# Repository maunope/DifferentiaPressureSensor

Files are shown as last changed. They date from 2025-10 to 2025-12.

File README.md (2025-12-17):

# ESP32-S3 Differential Pressure Datalogger

This project is a datalogger built on the ESP32-S3 platform using the ESP-IDF framework. It's designed to read environmental data from a BMP280 sensor, display it on an OLED screen with a menu-driven interface, and log the data to an SD card. The system uses a DS3231 Real-Time Clock (RTC) for accurate timestamping and exposes the SD card as a USB Mass Storage Device for easy data access.

Please refer to the following main guides for usage guidance and documentation:

*   **[User Interface Guide](UI_GUIDE.md)**: A complete guide to the on-screen menu system and controls.
*   **[Web UI Guide](WEB_UI.md)**: Instructions for using the web interface to manage files.
*   **[Software Architecture](SOFTWARE_ARCHITECTURE.md)**: An in-depth look at the software design, tasks, and communication mechanisms.
*   **[Board Design](BOARD_DESIGN.md)**: Details on the custom PCB, hardware components, and pinout.

## Overview

### Key Features

*   **Sensor Datalogging**: Periodically reads:
    *   Temperature and atmospheric pressure from a BMP280 sensor.
    *   Differential pressure from an Omron D6F-PH sensor.
    *   LiPo battery voltage and percentage.
    *   Device uptime in seconds.
*   **Dual-Mode Data Smoothing**: Configurable Kalman filtering is applied to all sensor readings. The system uses two distinct sets of filter parameters for "Normal" and "High-Frequency" logging modes. All parameters (`kf_*_q`, `kf_*_r`, `kf_*_q_hf`, `kf_*_r_hf`) can be customized in `config.ini`. If high-frequency (`_hf`) parameters are omitted, the system automatically calculates sensible defaults based on the normal-frequency values.
*   **SD Card Storage**: Logs sensor data to CSV files on an SD card, with support for file rotation based on size (1MB limit, approx. 2 weeks of recording at 1 point per minute).
*   **Real-Time Clock (RTC)**: Utilizes a DS3231 RTC for accurate timestamps. The system can synchronize its time from the RTC on startup.
*   **OLED Display & UI**: Features a menu-driven user interface on an OLED display, controlled by a rotary encoder with a push-button. The UI displays:
    *   Real-time sensor data (temperature, pressure, differential pressure, battery status).
    *   Current local timestamp (CET/CEST).
    *   SD card write status.
    *   Persistent status icons for battery level, charging status, and SD card write errors.
    *   A settings menu to manage the RTC, SD card, view configuration, and display a QR code linking to the project repository.
*   **NTP Time Sync**: Can synchronize the RTC with an NTP server over Wi-Fi.
*   **Web Server**: Can start a web server to allow downloading and previewing logged data files directly from a web browser.
*   **Multiple Sampling Modes**: Supports "Normal", "High Frequency", and "Paused" logging modes, selectable via the UI.
*   **Robust Power Management**: Implements a command-driven deep sleep cycle to conserve battery. The datalogger task explicitly signals when it's safe to sleep, preventing race conditions and ensuring data integrity. The device wakes up on a timer for the next log or via user interaction. A safety threshold on battery voltage avoids data corruption when measured battery voltage is too low to guarantee stable power to the 3.3V rail.
*   **Web File Management**: The web interface allows users to list, preview, download, and delete log files directly from the device.
*   **Exclusive File System Access**: To prevent data corruption, the system ensures that only one component (Datalogger, Web Server, or USB Mass Storage) can access the SD card at a time. For example, starting the web server will pause the datalogger, and connecting the device to a PC will disable both the web server and the datalogger.
*   **Configuration & Persistence**:
    *   **Permanent Settings**: Key parameters like sleep intervals, Wi-Fi credentials, and sensor models can be configured via a `config.ini` file on the SD card. These settings are loaded into flash memory and persist across reboots.
    *   **Session Settings**: UI-selected modes (like "High Frequency" or "Paused") are stored in RTC memory and persist through deep sleep cycles, but will be reset to their default values after a full power cycle or reboot.
*   **RTOS-based**: Built on FreeRTOS, with separate tasks for data logging and UI rendering for a responsive and robust application.

### Hardware Components

*   **Microcontroller**: ESP32-S3
*   **Sensors**:
    *   BMP280: Barometric Pressure and Temperature (I2C)
    *   Omron D6F-PH: Differential Pressure (I2C)
*   **Storage**:
    *   MicroSD Card Slot (SPI)
*   **Display**:
    *   OLED Display (I2C)
*   **User Input**:
    *   Rotary Encoder with Push-button
*   **Timekeeping**:
    *   DS3231 Real-Time Clock (I2C)
*   **Power**:
    *   LiPo Battery with a voltage divider for monitoring.

For more details on the custom PCB, see the [board design documentation](BOARD_DESIGN.md).

## Hardware Notes

### DS3231 RTC Configuration

Please be aware that this firmware automatically configures any connected DS3231 Real-Time Clock with specific default settings upon boot. These settings are optimized for low-power operation and resilience. For details on the exact register values being set, please refer to the `readme.md` file located in the `lib/i2c_ds3231/` directory.

### Usage

1.  **Configuration**: Copy the `config_sample.ini` file to the root of your SD card and rename it to `config.ini`. Edit this file to set your Wi-Fi credentials, sensor model, and other parameters.
2.  **Operation**: The device is controlled with the rotary encoder and its built-in push-button. For a detailed explanation of the menu system and on-screen information, please see the User Interface Guide.
3.  **Web Interface**: When the web server is active, you can manage files from your browser. See the Web UI Guide for more details.
## Software & Libraries

*   **Framework**: ESP-IDF
*   **RTOS**: FreeRTOS
*   **Component Management**: Dependencies like `qrcode` and `tinyusb` are managed by the ESP-IDF Component Manager via the `idf_component.yml` file. The `esp_tinyusb` component for USB Mass Storage is enabled and configured directly through `menuconfig`, with settings reflected in the PlatformIO build profiles.
*   **Software Architecture**: The project is built on a multi-tasking architecture using FreeRTOS. For a detailed explanation of the tasks and how they communicate, see the Software Architecture Guide.
*   **Custom Libraries (located in `lib/`)**: This project uses a modular structure with several custom libraries. Click on a library name to see its specific documentation.
    *   `config_manager`: Handles loading configuration from an INI file.
    *   `i2c_bmp280`: Driver for the BMP280 sensor.
    *   `i2c_d6fph`: Driver for the Omron D6F-PH sensor.
    *   `i2c_ds3231`: Driver for the DS3231 RTC.
    *   `i2c_oled`: Driver for the OLED display.
    *   `kalman`: kalman filter implementation.
    *   `lipo_battery`: Logic for reading battery voltage.
    *   `ntp_client`: Helper for synchronizing time from an NTP server.
    *   `rotary_encoder`: Driver for the rotary encoder input.
    *   `spi_sdcard`: High-level manager for SD card operations and USB MSC.
    *   `ui`: Manages the complete user interface, menu, and pages. See the UI Guide.
    *   `web_server`: Provides a web interface for downloading log files. See the Web UI Guide.
    *   `wifi_manager`: Centralizes Wi-Fi connection and disconnection logic.

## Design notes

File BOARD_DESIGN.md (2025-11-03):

# Differential Pressure Datalogger - PCB Design

This directory contains the KiCad project files for the custom PCB designed for the ESP32-S3 Differential Pressure Datalogger.

## Board Overview

The board is designed to be a compact, battery-powered datalogging platform. It integrates all the necessary components for sensing, data storage, user interaction, and power management.

The following diagram shows how the main peripherals are connected to the ESP32 microcontroller:

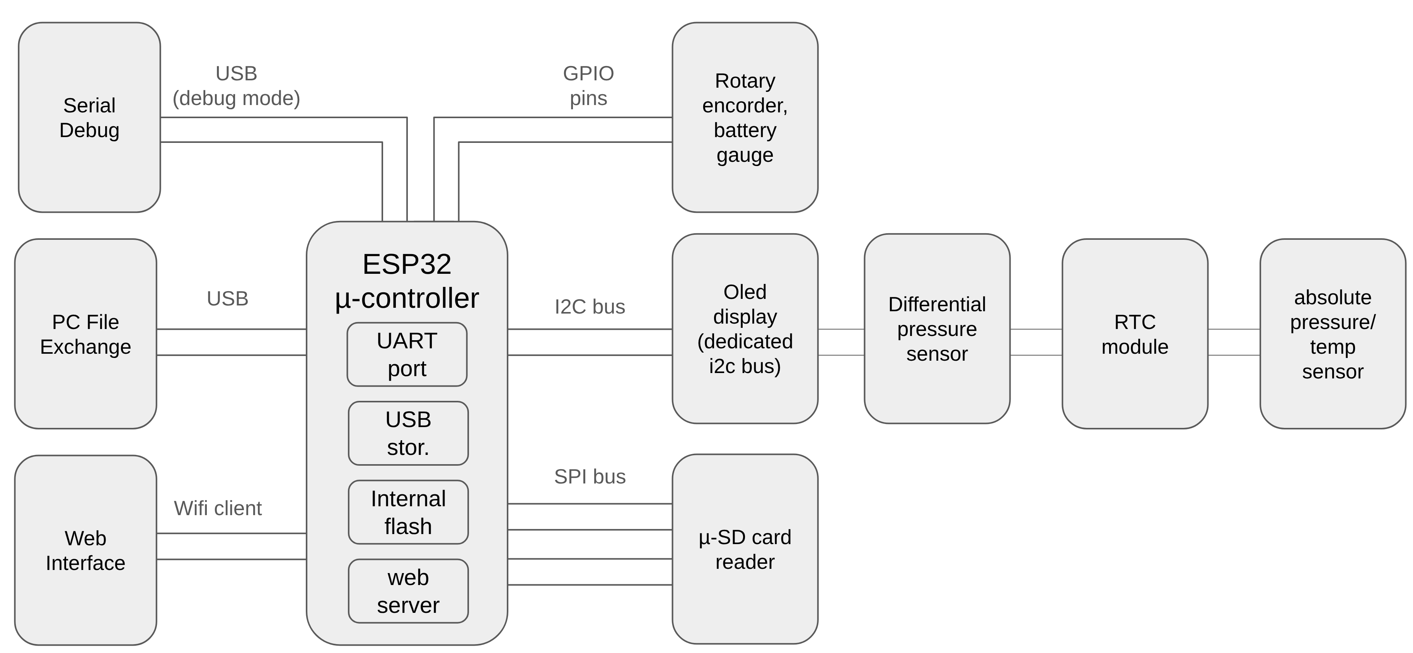
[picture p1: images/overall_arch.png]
Overall Architecture


The following image shows a render of the custom PCB layout:

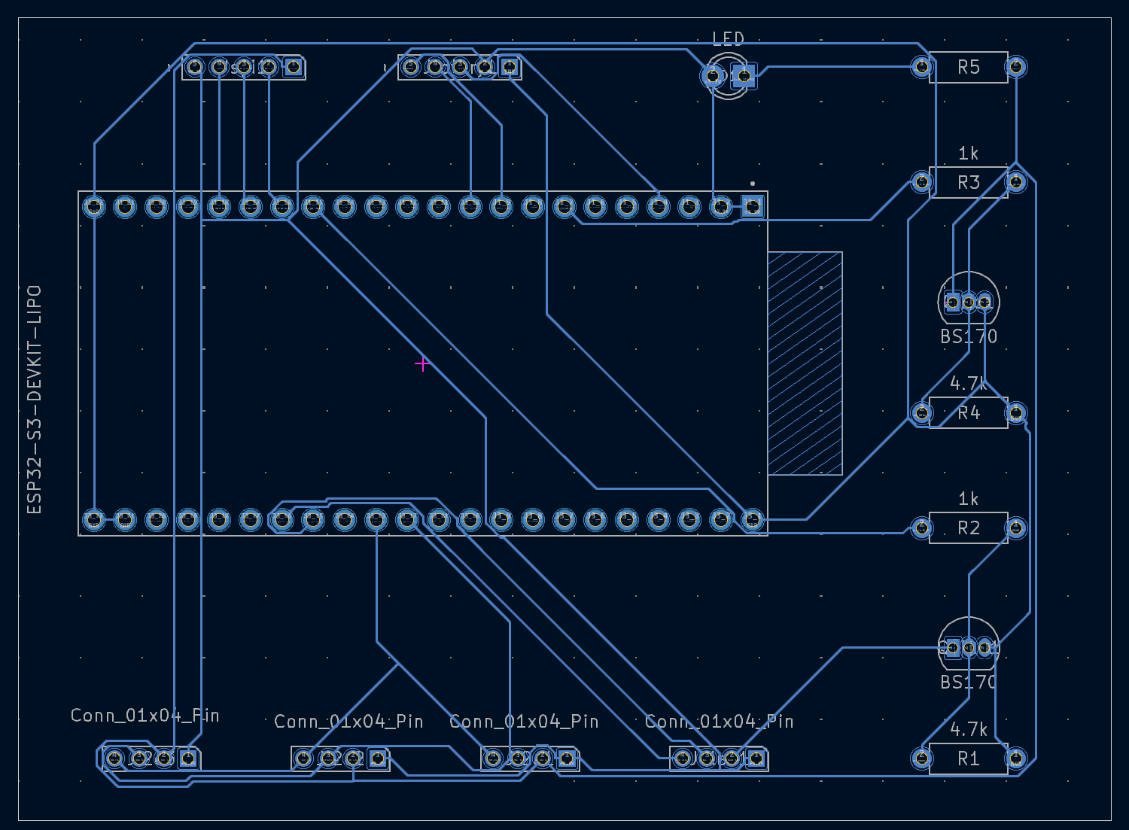
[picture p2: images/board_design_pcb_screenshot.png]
PCB Layout Screenshot


## Hardware & Compatibility

This project was developed and tested on the following hardware:

*   **[OLIMEX ESP32-S3-DevKit-LiPo](https://github.com/OLIMEX/ESP32-S3-DevKit-LiPo)**: This board was used for much of the development. It features a built-in LiPo battery charger and management circuit, which works seamlessly with the software's battery monitoring capabilities.
*   **Generic ESP32-S3 Dev-board**: Testing was also performed on a no-brand ESP32-S3 development board.

The software is designed to be portable and is expected to work on any ESP32-S3 based board with the correct peripheral connections. The only feature that is highly dependent on the specific board's hardware implementation is the **battery gauging**, which requires a specific voltage divider circuit on the ADC pin as detailed in the pinout table.

### Key Components

*   **Microcontroller**: ESP32-S3-WROOM-1 module.
*   **Sensors**:
    *   I2C BMP280 for atmospheric pressure and temperature.
    *   I2C [Omron D6F-PH](https://omronfs.omron.com/en_US/ecb/products/pdf/en-d6f_ph.pdf) for differential pressure. The software is written to support the `D6F-PH-0505AD3` (+/- 50 Pa), `D6F-PH-0025AD1` (+/- 250 Pa), and `D6F-PH-5050AD4` (+/- 500 Pa) models, selectable via the `config.ini` file.
*   **Timekeeping**: A generic **DS3231** I2C Real-Time Clock (RTC) module with a backup battery.
*   **Storage**: A **SPI bus** microSD card reader for data logging.
*   **User Interface**:
    *   2.42 Inch 128x64 I2C OLED display. (these often come configured for SPI and require some jumper soldering to be repurposed for I2C). 
    *   A standard 5-pin rotary encoder with a push-button.
*   **Connectivity**: USB-C for programming, power, and accessing the SD card as a Mass Storage Device.
*   **Power**: 3.7V LiPo battery with integrated protection circuitry. 

Apart form the Omron differential pressure sensor, all other devices are run of the mill stuff, easy to source from Aliexpress/Amazon and often icluded in esp32/Arudino starter kits. 

### Power System

All components used in this project are **3.3V devices**. It is critical **not to mix 5V and 3.3V logic levels** in the same circuit, as this would damage the components, especially the Omron D6F-PH sensor which is not 5V tolerant.

The custom PCB design primarily consists of pin headers (I2C, SPI, etc.) to connect these components in their breakout board form. The other components on the board are standard passives like resistors, along with BS170 MOSFETs for power control and JST connectors for external hardware.

The BS170 mosfets can be replaced with pretty much any N channel mosfet that can be turned on with 3.3V gate voltage, **IRLZ34N** have been tested and work just fine.

## Hardware Deep Sleep Implementation

To achieve ultra-low power consumption (under 1mA) during deep sleep, the board implements a hardware power-gating strategy. Two separate GPIO pins are used to control the power supply to different sets of peripherals:

*   **`DEVICES_POWER` (GPIO 15)**: This pin controls a MOSFET that supplies power to the main I2C bus peripherals (BMP280, D6F-PH) and the SD card. Before entering deep sleep, the ESP32 sets this pin low, completely cutting power to these components. This is the primary mechanism for power saving, reducing consumption by over 85%. The DS3231 RTC is on a separate, always-on power rail to maintain timekeeping.
*   **`OLED_POWER` (GPIO 16)**: This pin independently controls the power to the OLED display. This allows the screen to be turned off after a period of inactivity, even while the rest of the device is still running and logging data.

This hardware design allows the software to aggressively manage power, ensuring long battery life for a portable datalogger.

## Pinout

The following table details the GPIO connections for the main peripherals.

| Peripheral | Pin Name | ESP32-S3 GPIO | Notes |
| --- | --- | --- | --- |
| **Power Control** | `DEVICES_POWER` | 7 | Controls power to sensors/peripherals |
| | `OLED_POWER` | 15 | Controls power to the OLED display |
| | `I2C0_SCL` | 36 | |
| | `I2C0_SDA` | 35 |
| **OLED I2C Bus** | `I2C1_SCL` | 45 | Dedicated bus for the display |
| | `I2C1_SDA` | 48 | |
| **SD Card (SPI)** | `SPI_MOSI` | 12 | Standard SPI pins for SD card |
| | `SPI_MISO` | 10 | |
| | `SPI_CLK` | 11 | |
| | `SPI_CS` | 13 | |
| **Rotary Encoder**  | `ENC_A` | 4 | |
| | `ENC_B` | 16 | |
| | `ENC_BTN` | 17 | Also used as a deep sleep wakeup pin  |
| **Battery Monitor** | `BATT_PWR` | 5 | Detects external power |
| | `BATT_ADC` | 6 | ADC input for voltage measurement |

## I2C Bus Considerations

When extending the I2C bus, especially with longer cables, it's crucial to consider the impact of cable capacitance. Excessive capacitance can degrade signal integrity, leading to communication errors or complete bus failure. It is  recommended to keep total I2C bus length below 2-3 meters (total of all paralleled cables) to stay within acceptable capacitance limits.

To improve reliability over longer distances, several strategies can be employed:

*   **Pull-up Resistor Values**: The I2C bus requires pull-up resistors on both SDA and SCL lines. Keeping these values relatively low can help overcome capacitance effects. This board has been successfully tested with a total pull-up resistance of 3 kOhm (measured between Vcc and SDA/SCL pins) on a 4-meter cable length, operating at 100 kHz.
*   **Avoid Too Low Pull-ups**: While lower pull-up values are generally better for longer cables, care must be taken not to go too low. If I2C devices on the bus happen to have small internal pull-up resistors, they can effectively parallel with external resistors. The combined equivalent resistance should not cause overcurrents on i2c pins as going too low can lead to excessive current draw and signal distortion, 6mA capable pins should never be paired with less than 1kohm total pull up resistance.
*   **Cable Type**: Using twisted pair cables for SDA/SCL lines can significantly reduce noise and maintain signal integrity over distance. This practice helps in keeping the total bus capacitance below the recommended 400 picofarad limit for standard I2C operation.

For applications requiring longer I2C bus lengths or higher speeds, dedicated I2C bus extenders or buffers might be necessary.

## Design Files

This project was designed using **KiCad**. The main files are:

*   `DifferentialPressureSensor.kicad_pro`: The main KiCad project file.
*   `DifferentialPressureSensor.kicad_sch`: The schematic file.
*   `DifferentialPressureSensor.kicad_pcb`: The PCB layout file.

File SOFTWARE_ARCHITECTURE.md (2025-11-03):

# Software Architecture

This document provides an overview of the software architecture for the Differential Pressure Datalogger project. The system is built on the FreeRTOS real-time operating system, leveraging a multi-tasking design to ensure responsiveness and modularity.

## Core Principles

The architecture is designed around a few key principles:

*   **Separation of Concerns**: Each major function (data logging, user interface, input handling) is managed by its own dedicated task.
*   **Asynchronous Communication**: Tasks communicate primarily through message queues, which prevents tasks from blocking each other and keeps the system responsive.
*   **Shared State with Protection**: A central data structure, protected by a mutex, holds the current state and sensor data, providing a single source of truth for all tasks.

## Task Overview

The system is composed of several key tasks, each with a specific role and priority. In FreeRTOS, a higher number indicates a higher priority.

| Task Name | Priority | Core Responsibility |
| --- | :---: | --- |
| `rotary_encoder_task` | 7 | Hardware input processing (highest priority). |
| `uiRender_task` | 6 | User interface rendering and event handling. |
| `main_task` | 5 | Central controller and state management. |
| `datalogger_task` | 5 | Sensor reading and data logging to the SD card. |
| Web Server Task |  (ESP) | Handles HTTP requests (managed by `esp_http_server`). |

### `rotary_encoder_task` (Priority 7)

This is the highest-priority application task. Its sole responsibility is to capture and decode hardware interrupts from the rotary encoder. It detects rotation (clockwise/counter-clockwise) and button events (short and long presses), debounces them, and sends them as messages to the `uiRender_task` for processing. This high priority ensures that no user input is ever missed, even if other tasks are busy.

### `uiRender_task` (Priority 6)

This task is the heart of the user interface. It has a higher priority than the main logic to ensure the display is always responsive to user input.

*   **Receives**: Raw input events (e.g., `UI_EVENT_CW`, `UI_EVENT_BTN`) from the `rotary_encoder_task` via the `ui_event_queue`.
*   **Reads**: The shared `g_sensor_buffer` to get the latest data for display.
*   **Sends**: High-level application commands (e.g., `APP_CMD_START_WEB_SERVER`) to the `main_task` via `g_app_cmd_queue`.
*   **Responsibilities**: Manages menu navigation, renders all pages, and displays feedback from long-running commands (e.g., "Loading...").

### `main_task` (Priority 5)

This task acts as the central coordinator for the entire system. It runs a state machine that manages the device's overall behavior.

*   **Receives**: High-level commands from the `uiRender_task` via `g_app_cmd_queue`.
*   **Responsibilities**:
    *   Orchestrates complex sequences, such as starting the web server (which involves pausing the datalogger and connecting to Wi-Fi).
    *   Manages the power-saving logic, including inactivity timers and the deep sleep sequence.
    *   **Arbitrates SD Card Access**: Ensures exclusive access to the file system between the datalogger, web server, and USB Mass Storage.
    *   Ensures exclusive access to the SD card by preventing the web server from starting if USB Mass Storage is active, and stopping the web server if USB is connected.
    *   Handles system-level requests like NTP time sync and SD card formatting.

### `datalogger_task` (Priority 5)

This task handles all sensor reading and data storage.

*   **Receives**: Commands like `DATALOGGER_CMD_PAUSE_WRITES` and `DATALOGGER_CMD_RESUME_WRITES` from the `main_task`.
*   **Writes**: The latest sensor readings and status information to the shared `g_sensor_buffer`.
*   **Responsibilities**:
    *   Handles file system commands sent from other tasks, such as deleting a log file (`DATALOGGER_CMD_DELETE_FILE`).
    *   Periodically wakes up to read data from the BMP280, D6F-PH, and battery monitor.
    *   Formats the data into CSV format.
    *   Writes the data to the SD card.

## Communication Mechanisms

### Shared Data Buffer

*   **`g_sensor_buffer`**: A global `struct` that holds the most recent state of the entire system. This includes sensor values, battery status, SD card statistics, and web server status.
*   **`g_sensor_buffer_mutex`**: A mutex that protects `g_sensor_buffer` from concurrent access. Any task that needs to read from or write to the buffer must first acquire this mutex. To keep the system responsive, tasks are designed to hold the mutex for the shortest possible time.

### Message Queues

*   **`g_app_cmd_queue`**: Used to send high-level commands *to* the `main_task`. This decouples the UI from the application logic. For example, the UI sends `APP_CMD_START_WEB_SERVER`, and the `main_task` handles the multi-step process of making that happen.
*   **`g_datalogger_cmd_queue`**: Used to send specific commands *to* the `datalogger_task`, such as pausing or resuming SD card writes.
*   **`ui_event_queue`**: A dedicated queue for the `uiRender_task`. The `rotary_encoder_task` places raw input events here for the UI to process.
*   **`g_i2c_bus_mutex`**: Protects the main I2C bus (`I2C_NUM_0`), which is shared by multiple sensors (BMP280, DS3231, D6F-PH). This prevents tasks from attempting to communicate on the bus at the same time.
*   **`g_command_status_mutex`**: Protects the `g_command_status` variable. This variable is used for asynchronous feedback between the `main_task` and the `uiRender_task` for long-running operations like formatting the SD card or syncing with an NTP server.

## Exclusive File System Access

The SD card is a critical shared resource. To prevent file system corruption, all file system operations are protected by a dedicated mutex (`g_sdcard_mutex` in the `spi_sdcard` library). This ensures that only one operation (e.g., writing a log line, deleting a file, listing files for the web server) can occur at a time, even when multiple tasks are running concurrently.

There are three components that can access the SD card:

1.  **Datalogger Task**: The default owner, responsible for writing sensor data logs.
2.  **Web Server**: Allows a user to list, download, and delete files via a web browser.
3.  **USB Mass Storage (MSC)**: Allows a host computer to mount the SD card as a drive, which has the highest priority.

The access rules are as follows:

*   **USB Mass Storage has absolute priority.** If the device is connected to a PC and the SD card is mounted by the host computer, the `main_task` will automatically stop the web server (if it's running) and will prevent both the web server and the datalogger from starting. This gives the host computer exclusive control to ensure a stable connection and prevent data corruption.
*   **Concurrent Operation with Mutex Protection**: The `datalogger_task` (writing logs) and the Web Server task (listing/deleting files) can run at the same time. They do not need to pause each other. The low-level `g_sdcard_mutex` serializes their access to the SD card, preventing conflicts. For example, if the web server is deleting a file, the datalogger's attempt to write a new line will block on the mutex until the deletion is complete.
*   **Special Operations (Formatting)**: For destructive, long-running operations like formatting the SD card, the `main_task` still explicitly pauses the `datalogger_task` to ensure the file system is completely idle.
*   **Safe Ejection**: When connected as a USB Mass Storage device, it is highly recommended to use your operating system's "Eject" or "Safely Remove Hardware" feature before physically unplugging the device. This ensures all file operations are complete and helps prevent data corruption on the SD card.

This mutex-based approach provides more efficient and responsive operation than pausing entire tasks, while still guaranteeing data integrity.

## Power Management & Deep Sleep

The device is designed for low-power operation by using a deep sleep cycle. The `main_task` is responsible for managing the sleep and wake logic.

### Entering Deep Sleep

The device will enter deep sleep when all of the following conditions are met:

1.  The UI has been inactive for a configurable period (`inactivity_timeout_ms`), which causes the UI task to suspend.
2.  The `datalogger_task` has completed a write to the SD card and sent an `APP_CMD_LOG_COMPLETE_SLEEP_NOW` command to the `main_task`.
3.  The web server is not active at the time the sleep command is processed.

The sleep sequence is as follows:

1.  The `main_task` receives the `APP_CMD_LOG_COMPLETE_SLEEP_NOW` command.
2.  It verifies that the UI is suspended and the web server is inactive.
3.  It sends a `DATALOGGER_CMD_PAUSE_WRITES` command to the `datalogger_task`.
4.  It waits for the `datalogger_task` to confirm it has suspended itself.
5.  Once paused, it de-initializes the SD card, Wi-Fi, and cuts power to the main peripheral power rail.
6.  It saves critical state variables (e.g., the timestamp of the last write, total uptime) to RTC memory, which persists through deep sleep.
7.  It configures two wakeup sources for the ESP32-S3: 
    *   **GPIO**: A press on the rotary encoder button.
    *   **Timer**: A timer set by the `sleep_duration_ms` configuration value.
8.  It calls `esp_deep_sleep_start()` to enter deep sleep.

### Waking Up

The device wakes up when either the timer expires or the user presses the button.

*   **On Timer Wakeup**: The device wakes up to perform a data logging cycle. The UI remains off to conserve power. After the logging is complete, it immediately prepares to enter deep sleep again.
*   **On GPIO Wakeup (User Activity)**: The device performs a full boot sequence, powering on the OLED display and initializing the UI. The user can then interact with the device normally.

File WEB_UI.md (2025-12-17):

# Web User Interface Guide

This document explains the features and functionality of the web-based user interface, which can be accessed when the device's web server is active.

## Overview

The web UI provides a convenient way to monitor the device, view live data, and manage log files directly from a web browser on a computer or smartphone connected to the same Wi-Fi network.

The interface is divided into three main sections:
1.  **Live Sensor Data**: A real-time dashboard of sensor readings.
2.  **File Browser**: A list of all data log files stored on the SD card.
3.  **File Previewer**: An interactive tool for viewing the contents of log files without downloading them.
## Live Sensor Data

The panel at the top of the page displays the most recent data read from the device's sensors. This data is automatically refreshed every 5 seconds and includes:

*   **Timestamp**: The current date and time from the device's RTC.
*   **Temperature**: Ambient temperature in Celsius.
*   **Pressure**: Atmospheric pressure in kilopascals (kPa).
*   **Diff. Pressure**: Differential pressure in Pascals (Pa).
*   **Battery**: Voltage, percentage, and charging status.

If the web page fails to fetch data, a banner will appear with a "Retry" button to re-establish the connection.

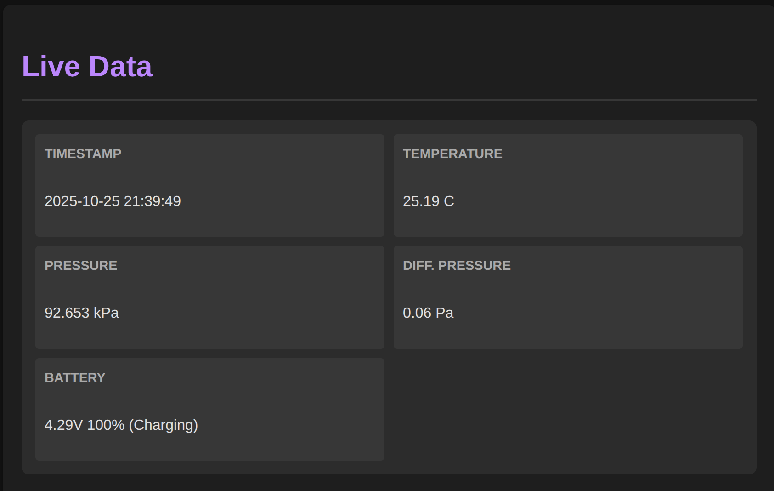
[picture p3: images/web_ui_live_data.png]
Live Sensor Data


## File Browser

This section lists all files found on the SD card, sorted by the most recently modified. Each entry provides the following information and actions:

*   **Filename**: The name of the log file. Clicking this link will download the file directly to your computer.
*   **File Metadata**: The file size and the date it was last modified.
*   **Preview Button**: Opens the interactive File Previewer for that file.
*   **Delete Button**: Permanently deletes the file from the SD card after a confirmation prompt.

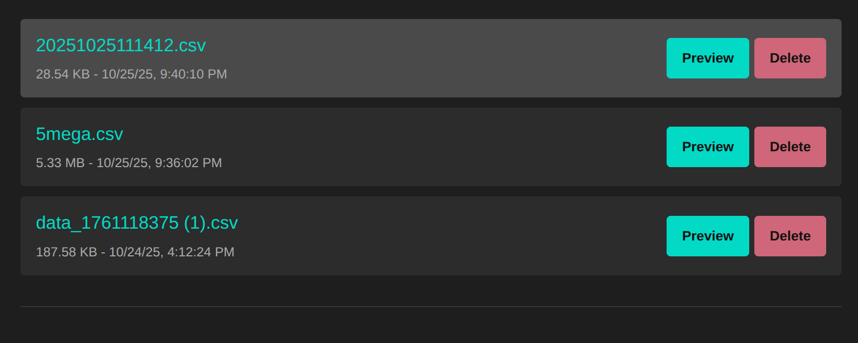
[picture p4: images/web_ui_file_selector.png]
File Browser


## File Previewer

The File Previewer is a powerful tool for inspecting log data directly on the device.

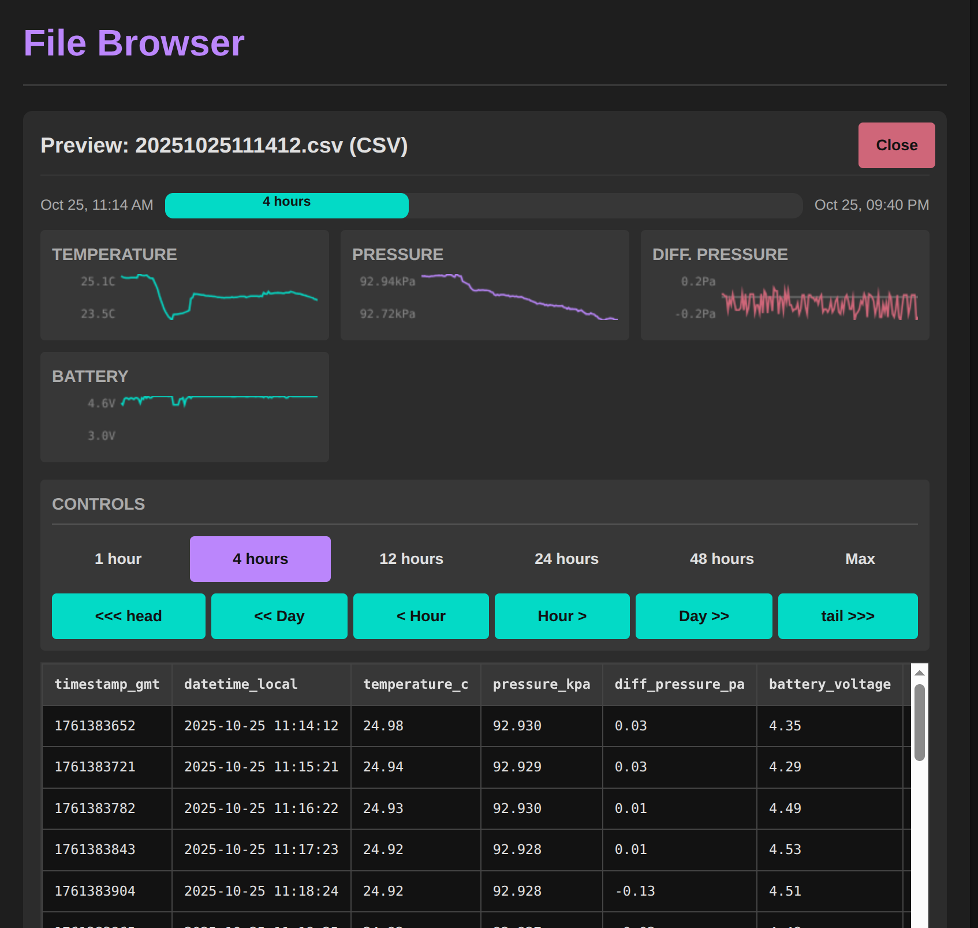
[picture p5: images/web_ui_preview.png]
File Previewer


### CSV vs. Raw Text Files

The previewer automatically detects the file type:
*   **CSV Files**: If the file is recognized as a CSV log, it will be displayed in a scrollable table with a header. At the top, sparkline graphs provide a quick visual summary of the data currently loaded in the table.
*   **Non-CSV Files**: If the file is not a standard log file (e.g., `config.ini`), its contents will be displayed as plain, raw text.

### Navigating CSV Data

The sparkline graphs are designed to provide a quick, at-a-glance overview of the data trends within the currently loaded time window. This is especially useful for getting a quick sense of the data in the field with minimal effort, even without an internet connection.

For a more thorough analysis, especially with very large files, it is recommended to download the CSV file and use a dedicated tool. You can open the file in any spreadsheet program (like Microsoft Excel, Google Sheets, or LibreOffice Calc) or use online data visualization tools that allow you to upload CSV files, such as:
*   CSV Plot
*   Draxlr

Additionally, mobile apps like Smart CSV are excellent for processing and visualizing entire data files on the go.

The previewer is designed to handle very large files efficiently by only loading small chunks of data at a time.

#### Time Window and Navigation

The previewer has two sets of controls for navigation:

1.  **Scale Buttons (`1 hour`, `4 hours`, etc.)**: These buttons set the **size of the time window** to load. When you select a scale, the previewer fetches a chunk of data that covers that duration.
    *   **Performance Note**: For very large files, using a wide time window (like "24 hours" or "Max") can be sluggish, as the device needs to process more data to find the correct starting point. For quicker navigation, it's often better to use a smaller window and jump through the file.

2.  **Jump Buttons (`<<< head`, `< Hour`, `Day >>`, etc.)**: These buttons perform **windowed navigation**, allowing you to "jump" through the file. When you click one of these buttons:
    *   The currently displayed data is **replaced** with a new chunk of data from a different part of the file, based on the button you clicked (e.g., `Day >>` jumps forward 24 hours).
    *   This is the fastest way to move through large files, as it avoids loading all the data in between.

For extremely large or dense files, the most efficient way to perform a full analysis is to download the file and open it on your computer.

#### Data View Toggle

When previewing a CSV file, the sparkline graphs can display either the raw sensor data or the smoothed (Kalman-filtered) data. The filter parameters are configured in `config.ini`.

*   **Smoothed View (Default)**: This view shows the data after it has been processed by the Kalman filter. It is generally cleaner and easier to interpret, as it removes sensor noise.
*   **Raw View**: This view shows the unprocessed data directly from the sensors. It is useful for diagnostics and for observing the unfiltered sensor behavior.

You can switch between these views using the **"Smoothed"** and **"Raw"** toggle buttons located in the "Controls" panel above the data table.

The system uses two distinct sets of Kalman filter parameters: one for normal logging (`kf_*_q`, `kf_*_r`) and one for high-frequency logging (`kf_*_q_hf`, `kf_*_r_hf`). All of these can be configured in `config.ini`. If the high-frequency parameters are not specified, the device will automatically calculate appropriate defaults based on the normal-frequency settings, providing a good baseline for both logging speeds out-of-the-box.

#### Scrolling

You can use your mouse or trackpad to scroll through the data that is currently loaded in the preview table. Scrolling does **not** load new data from the file. To navigate to a different part of the file, you must use the **Scale** and **Jump** buttons.

When you click a navigation button (e.g., `Day >>`), the currently displayed data is replaced with a new chunk from the file, and the scroll position is reset to the top of the new chunk.

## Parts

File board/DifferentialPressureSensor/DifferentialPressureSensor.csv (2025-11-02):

Reference | Qty | Value | DNP | Exclude from BOM | Exclude from Board | Footprint | Datasheet
D1 | 1 | LED |  |  |  | LED_THT:LED_D3.0mm | ~
Ji2c1,Ji2c2,Ji2c3,Joled1 | 4 | Conn_01x04_Pin |  |  |  | Connector_PinHeader_2.00mm:PinHeader_1x04_P2.00mm_Vertical | ~
Jrotary1,Jspi1 | 2 | ~ |  |  |  | Connector_PinHeader_2.00mm:PinHeader_1x05_P2.00mm_Vertical | ~
Qi2c1,Qoled1 | 2 | BS170 |  |  |  | Package_TO_SOT_THT:TO-92_Inline | https://www.onsemi.com/pub/Collateral/BS170-D.PDF
R1,R4,R5 | 3 | 4.7k |  |  |  | Resistor_THT:R_Axial_DIN0207_L6.3mm_D2.5mm_P7.62mm_Horizontal | ~
R2,R3 | 2 | 1k |  |  |  | Resistor_THT:R_Axial_DIN0207_L6.3mm_D2.5mm_P7.62mm_Horizontal | ~
U1 | 1 | ESP32-S3-DEVKIT-LIPO |  |  |  | Olimex ESP32 S3 LiPo Devkit:XCVR_ESP32-S3-DEVKIT-LIPO

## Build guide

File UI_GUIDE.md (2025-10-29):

# User Interface Guide

This guide explains how to navigate and use the user interface of the Differential Pressure Datalogger. The UI is controlled using a single rotary encoder with a built-in push-button.

## Controls

*   **Rotate Clockwise (CW)**: Navigates **down** in menus or cycles forward through pages.
*   **Rotate Counter-Clockwise (CCW)**: Navigates **up** in menus or cycles backward through pages.
*   **Short Press**:
    *   In a menu, it **selects** the highlighted item. This may enter a submenu, trigger an action, or show an information page.
    *   On an information page (like "About" or "Sensor Data"), it **returns to the main menu**.
*   **Long Press (Hold for ~1 second)**: From any menu screen, it acts as a "home" button, immediately returning you to the **Sensor Data screen**.

## Status Icons

The top-right corner of the screen displays persistent icons that provide at-a-glance information about the device's status.

*   **Battery Icon**: Shows the current battery charge level. The fill level represents the remaining charge.

    ```
    +--------------------+
    | Main Menu      [[]] <-- Battery Icon
    | ...                |
    +--------------------+
    ```

*   **Charging Icon**: When the device is connected to USB power, a lightning bolt symbol appears **inside** the battery icon.

    ```
    +--------------------+
    | Main Menu      [[#]] <-- Charging Icon
    | ...                |
    +--------------------+
    ```

*   **SD Card or Sensor Error**: If the device fails to write to the SD card or a sensor fails to initialize or read, an **error icon (!!)** will appear to the **left** of the battery icon. This icon persists until the condition is resolved.

    ```
    +--------------------+
| Main Menu   !! [[]] <-- Error Icon
    | ...                |
    +--------------------+
    ```

*   **USB Connection Icon**: When the device is connected to a computer and mounted as a USB drive, a **USB plug icon** will appear. This indicates that the SD card is accessible from your computer. While this icon is active, other status icons (like SD Error, Paused, and High-Frequency) are hidden, as logging is temporarily suspended.

*   **Paused Icon**: When data logging is paused via the "Sampling Mode" menu, a **pause icon (||)** will appear to the left of the battery icon. In this mode, the device will not write any new data to the SD card and will not enter deep sleep automatically.

    ```
    +--------------------+
| Main Menu   || [[]] <-- Paused Icon
    | ...                |
    +--------------------+
    ```

*   **High-Frequency Mode**: When enabled, a **fast-forward icon (>>)** appears to the left of the battery icon. This indicates that the device is using shorter logging and sleep intervals.

    ```
    +--------------------+
| Main Menu   >> [[]] <-- HF Mode Icon
    | ...                |
    +--------------------+
    ```

## Main Screens

### Sensor Data Screen (Home)

This is the default screen shown on startup. It is composed of two pages that you can cycle through by **rotating the encoder**. A **short press** on the button will take you to the Main Menu.

#### Page 1: Sensor Readings

This page shows the primary environmental sensor data, now with icons for clarity.

```
+--------------------+
| Sensor Data        |
|                    |
| 2023-10-27 14:30:15|  <-- Current Date & Time (CET)
|                    |
| T: 24.51 C         |  <-- Temperature
| P: 101325 Pa       |  <-- Atmospheric Pressure
| DP: -2.34 Pa       |  <-- Differential Pressure
+--------------------+
```

#### Page 2: System Information

This page displays system-level information, including the persistent uptime and the time of the last successful write to the SD card.

```
+--------------------+
| Sensor Data        |
|                    |
| Uptime: 0:01:23:45 |  <-- Total awake time (D:HH:MM:SS)
|                    |
| lw: 14:30:05       |  <-- Time of last successful SD write
+--------------------+
```

### View Config Screen

This page allows you to view the current configuration parameters loaded from the `config.ini` file. You can scroll through the parameters using the rotary encoder.

```
+--------------------+
| View Config        |
| v_div_ratio        |
|  4.1333            |
| inactive_ms        |
|  30000             |
| sleep_ms           |
|  60000             |
+--------------------+
```

## Menu System

A short press on the button from the main data screen enters the menu system.

### Main Menu

```
+--------------------+
| Main Menu          |
|> Sensor data       |
|  Options >         |
|  Web Server >      |
|  High Freq. Mode   |
|  About             |
|                    |
|                    |
+--------------------+
```

*   **Sensor data**: Returns to the main data display screen.
*   **High Freq. Mode**: Enters a menu to enable or disable high-frequency logging mode. This mode is temporary and resets on reboot.
*   **Sampling Mode**: Enters a submenu to control the data logging behavior. These modes persist through deep sleep cycles but are reset to "Normal" on a full reboot.
*   **Web Server**: Enables a web server to allow data files download through WiFi, pauses data logging and disables sleep.
*   **Options**: Enters the `Options` submenu for device settings.
*   **About**: Displays a QR code and a short link to the project's GitHub repository.

### Sampling Mode Submenu

This menu allows you to change how the datalogger operates for the current session.

```
+--------------------+
| Sample Mode        |
|> High Frequency    |
|  Normal            |
|  Paused            |
|                    |
|                    |
|                    |
+--------------------+
```

### Web Server page

When you start the web server from the menu, the device will connect to your Wi-Fi and display a QR code and a URL on the OLED screen. You can scan the QR code or enter the URL into a web browser on a device connected to the same network.

```
+--------------------+
|                    |
|    ████████████    |
|    █ ▄▄▄▄▄▄ █ █    |
|    █ █▄█▄█▄ █ █    |
|    █▄▄▄▄▄▄▄█ █    |
|                    |
+--------------------+
```

*   **Download**: Click the "Download" button to save a CSV file to your device.
*   **Delete**: Click the "Delete" button to permanently remove a file from the SD card.
*   **Preview**: Click the "Preview" button to view the contents of a CSV file directly in your browser. This feature loads the file in chunks, making it fast and mobile-friendly. It includes a "sticky" header so you always see the column titles, and "Load More" / "Load All" buttons for viewing large files.

### Options Menu

```
+--------------------+
| Options            |
|> Real Time Clock > |
|  File System >     |
|  View Config       |
|  Back              |
|                    |
|                    |
+--------------------+
```

*   **Real Time Clock**: Enters a submenu for time-related actions.
*   **File System**: Enters a submenu for SD card actions.
*   **View Config**: Shows the configuration viewer page.
*   **Back**: Returns to the Main Menu.

### Real Time Clock Submenu

```
+--------------------+
| Real Time Clock    |
|> Set Time (build)  |
|  Sync NTP          |
|  Back              |
|                    |
|                    |
|                    |
+--------------------+
```

*   **Set Time (build)**: Sets the DS3231 RTC to the time the firmware was compiled. A confirmation screen will appear.
*   **Sync NTP**: Attempts to connect to Wi-Fi (using credentials from `config.ini`) and synchronize the RTC with an internet time server.

### File System Submenu

```
+--------------------+
| File System        |
|> View Stats        |
|  Format SD         |
|  Back              |
|                    |
|                    |
|                    |
+--------------------+
```

*   **View Stats**: Shows a page with SD card statistics, including free space and file count.
*   **Format SD**: **(Warning!)** Enters a confirmation screen to format the SD card, which will erase all data.

### About Page

Selecting "About" from the Main Menu will display a QR code. Scan this with your phone to visit the project's source code repository.

```
+--------------------+
|                    |
|    ████████████    |
|    █ ▄▄▄▄▄▄ █ █    |
|    █ █▄█▄█▄ █ █    |
|    █▄▄▄▄▄▄▄█ █    |
|                    |
+--------------------+
```

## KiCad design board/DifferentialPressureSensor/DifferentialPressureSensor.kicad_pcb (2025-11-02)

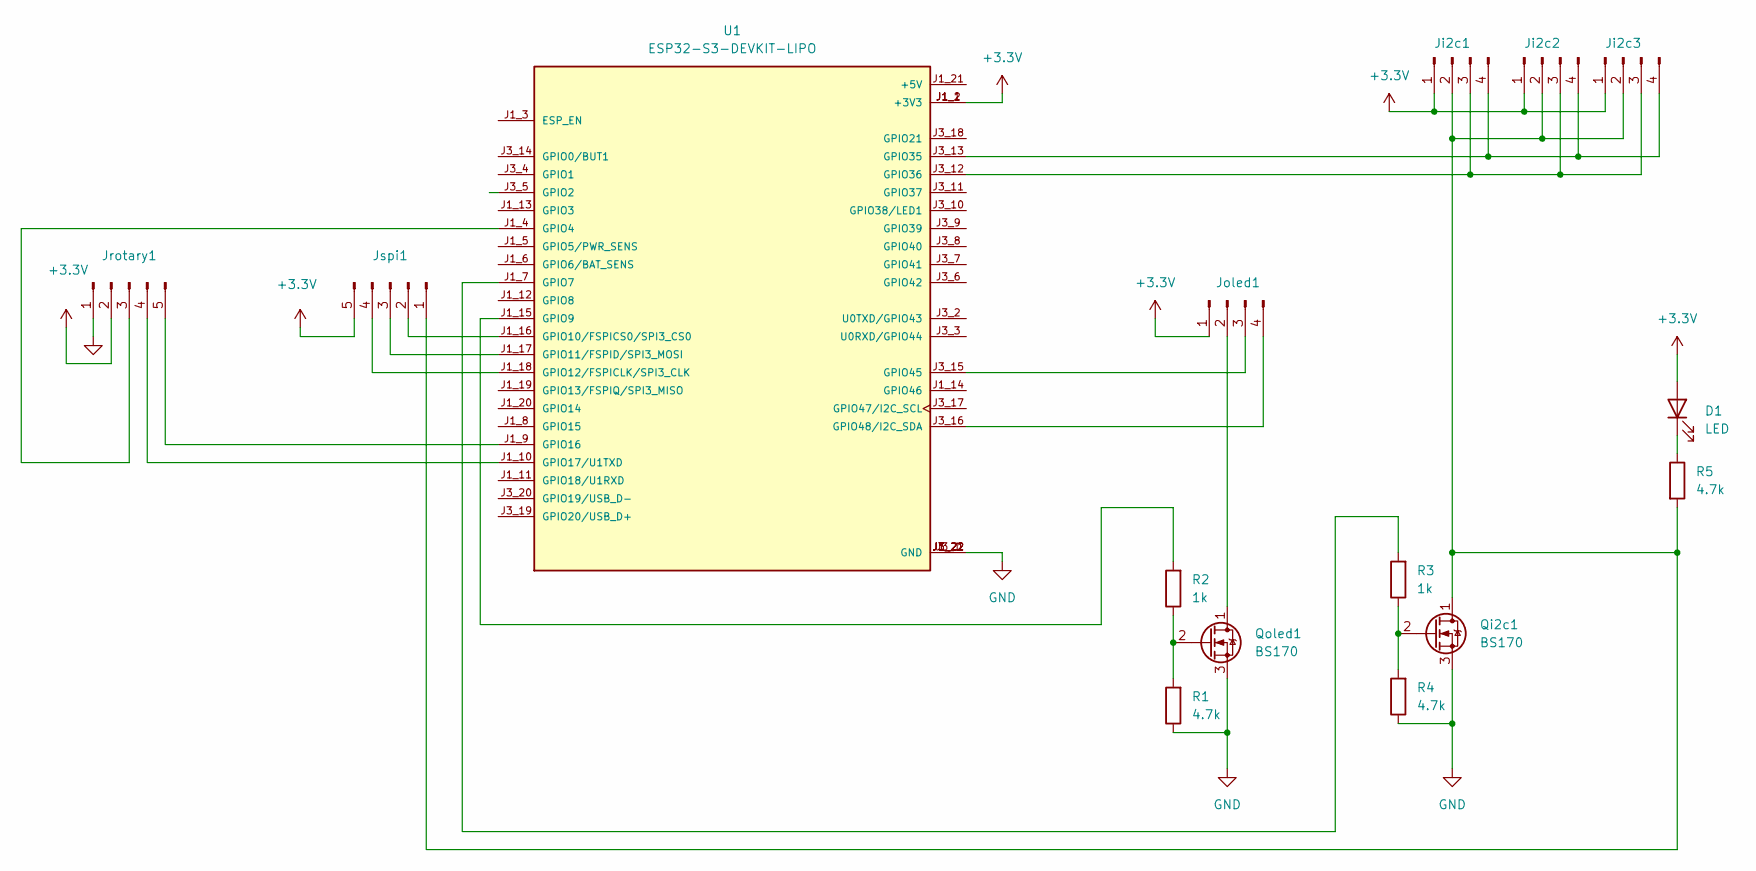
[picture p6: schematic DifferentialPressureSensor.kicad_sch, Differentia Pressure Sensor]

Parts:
D1: LED; LED_D3.0mm
Ji2c1, Ji2c2, Ji2c3: Conn_01x04_Pin; PinHeader_1x04_P2.00mm_Vertical
Joled1: Conn_01x04_Pin; PinHeader_1x04_P2.00mm_Vertical
Jrotary1: PinHeader_1x05_P2.00mm_Vertical
Jspi1: PinHeader_1x05_P2.00mm_Vertical
Qi2c1: BS170; TO-92_Inline
Qoled1: BS170; TO-92_Inline
R1, R4, R5: 4.7k; R_Axial_DIN0207_L6.3mm_D2.5mm_P7.62mm_Horizontal
R2, R3: 1k; R_Axial_DIN0207_L6.3mm_D2.5mm_P7.62mm_Horizontal
U1: ESP32-S3-DEVKIT-LIPO; XCVR_ESP32-S3-DEVKIT-LIPO; PARTREV B

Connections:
+3.3V: D1.2 (A), Ji2c1.1, Ji2c2.1, Ji2c3.1, Joled1.1, Jrotary1.2, Jspi1.5, U1.J1_1 (+3V3), U1.J1_2 (+3V3)
GND: Jrotary1.1, Qi2c1.3 (S), Qoled1.3 (S), R1.1, R4.1, U1.J1_22 (GND), U1.J3_1 (GND), U1.J3_21 (GND), U1.J3_22 (GND)
unnamed: D1.1 (K), R5.1
unnamed: Ji2c1.2, Ji2c2.2, Ji2c3.2, Jspi1.1, Qi2c1.1 (D), R5.2
unnamed: Ji2c1.3, Ji2c2.3, Ji2c3.3, U1.J3_12 (GPIO36)
unnamed: Ji2c1.4, Ji2c2.4, Ji2c3.4, U1.J3_13 (GPIO35)
unnamed: Joled1.2, Qoled1.1 (D)
unnamed: Joled1.3, U1.J3_15 (GPIO45)
unnamed: Joled1.4, U1.J3_16 (GPIO48/I2C_SDA)
unnamed: Jrotary1.3, U1.J1_4 (GPIO4)
unnamed: Jrotary1.4, U1.J1_10 (GPIO17/U1TXD)
unnamed: Jrotary1.5, U1.J1_9 (GPIO16)
unnamed: Jspi1.2, U1.J1_16 (GPIO10/FSPICS0/SPI3_CS0)
unnamed: Jspi1.3, U1.J1_17 (GPIO11/FSPID/SPI3_MOSI)
unnamed: Jspi1.4, U1.J1_18 (GPIO12/FSPICLK/SPI3_CLK)
unnamed: Qi2c1.2 (G), R3.1, R4.2
unnamed: Qoled1.2 (G), R1.2, R2.1
unnamed: R3.2, U1.J1_7 (GPIO7)
unnamed: R2.2, U1.J1_15 (GPIO9)

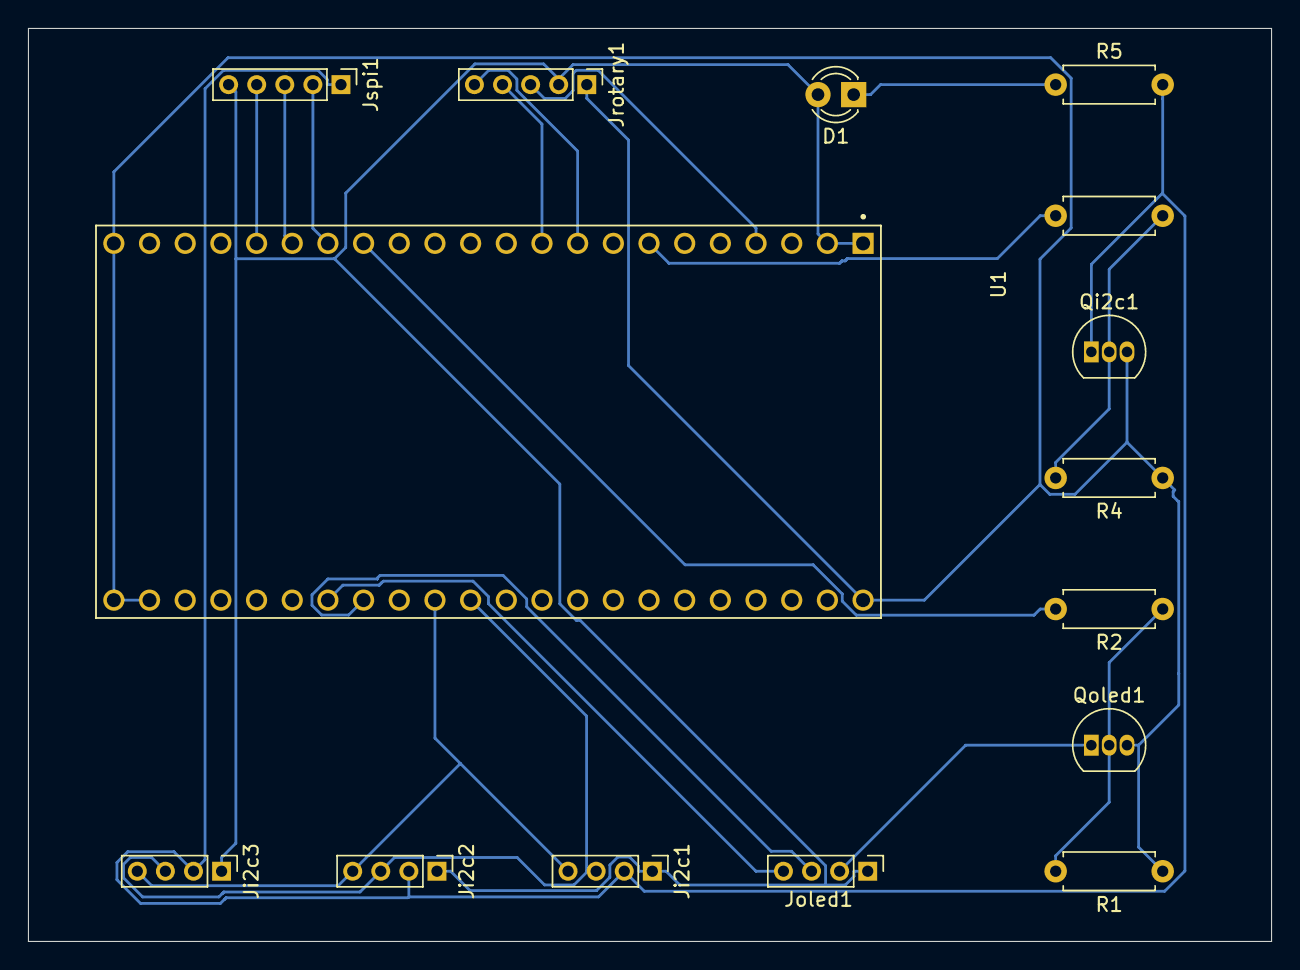
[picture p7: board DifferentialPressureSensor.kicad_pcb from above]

Board: 2 copper layers, 88.5 x 65.0 mm, 15 parts (0 on the bottom side), 19 nets.

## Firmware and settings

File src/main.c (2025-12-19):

// ESP-IDF script for reading I2C barometric sensor (BMP280) and rotary encoder,
// printing data to serial and a 2-line I2C LCD using a self-contained driver.

#include <stdio.h>
#include <string.h>
#include "freertos/FreeRTOS.h"
#include "freertos/semphr.h" // Required for semaphore
#include "freertos/task.h"
#include "freertos/queue.h"
#include "esp_system.h"
#include "esp_log.h"
#include "driver/i2c_master.h"
#include "driver/gpio.h"
#include "driver/rtc_io.h"
#include "sdkconfig.h"
#include "esp_rom_sys.h"
#include "esp_timer.h" // Required for esp_timer_get_time()
#include <time.h>
#include "esp_ota_ops.h"
#include <sys/time.h>
#include <sys/stat.h>
#include "esp_sleep.h"
#include "esp_sntp.h"
#include <unistd.h> // For unlink()
#include <errno.h>  // For errno
#include "esp_netif.h"

#include "../lib/i2c_bmp280/i2c_bmp280.h"
#include "../lib/i2c_d6fph/i2c_d6fph.h"
#include "../lib/i2c_ds3231/i2c_ds3231.h"
#include "../lib/i2c_oled/i2c_oled.h"
#include "../lib/rotary_encoder/rotary_encoder.h"
#include "../lib/spi_sdcard/spi_sdcard.h"
#include "../lib/buffers.h"
#include "../lib/config_manager/config_manager.h"
#include "../lib/lipo_battery/lipo_battery.h"
#include "../lib/ntp_client/ntp_client.h"
#include "../lib/wifi_manager/wifi_manager.h"
#include "../lib/web_server/web_server.h"
#include "ui_render.h"
#include "datalogger_task.h"
#include "config_params.h"
#include <math.h>
// DO NOT use pins 19 and 20, they are used by the flash memory
// DO NOT use pins 5 and 6, they are used for LiPo battery measurements unless you change the config

#define UNKNOWN_FILE_WRITE_STATUS 2

#define DEVICES_POWER_PIN GPIO_NUM_7
#define OLED_POWER_PIN GPIO_NUM_15

// --- I2C Configuration for peripherals ---
#define I2C_MASTER_NUM I2C_NUM_0
#define I2C_MASTER_SCL_IO GPIO_NUM_36
#define I2C_MASTER_SDA_IO GPIO_NUM_35
#define I2C_MASTER_FREQ_HZ 100000 // 100kHz I2C clock

// --- I2C Configuration for OLED ---
#define I2C_OLED_NUM I2C_NUM_1
#define I2C_OLED_SCL_IO GPIO_NUM_45
#define I2C_OLED_SDA_IO GPIO_NUM_48

// --- Rotary Encoder Configuration ---
#define ROTARY_ENCODER_PIN_A GPIO_NUM_4
#define ROTARY_ENCODER_PIN_B GPIO_NUM_16
#define ROTARY_ENCODER_BUTTON_PIN GPIO_NUM_17
#define BUTTON_DEBOUNCE_TIME_MS 100
#define ROTATION_DEBOUNCE_TIME_MS 20

// --- Battery ADC Configuration ---
#define BATTERY_PWR_PIN GPIO_NUM_5 // This pin is used to enable the battery voltage divider
#define BATTERY_ADC_PIN GPIO_NUM_6

// --- SD Card SPI Configuration ---
#define SD_CARD_SPI_MOSI_PIN GPIO_NUM_12
#define SD_CARD_SPI_MISO_PIN GPIO_NUM_10
#define SD_CARD_SPI_SCLK_PIN GPIO_NUM_11
#define SD_CARD_SPI_CS_PIN   GPIO_NUM_13

#define OLED_I2C_ADDR 0x3C
#define DS3231_I2C_ADDR 0x68
#define BMP280_I2C_ADDR 0x76
#define D6FPH_I2C_ADDR 0x6C

// --- RTC Memory for State Persistence ---
// These variables retain their values across deep sleep cycles.
static RTC_DATA_ATTR write_status_t rtc_last_write_status = WRITE_STATUS_UNKNOWN;
static RTC_DATA_ATTR time_t rtc_last_write_attempt_ts = 0; // This was a duplicate line
static RTC_DATA_ATTR time_t rtc_last_successful_write_ts = 0;
static RTC_DATA_ATTR datalogger_mode_t rtc_datalogger_mode = DATALOGGER_MODE_NORMAL;
static RTC_DATA_ATTR uint64_t rtc_total_awake_time_s = 0;
static RTC_DATA_ATTR uint64_t rtc_last_boot_time_ms = 0;

static const char *TAG = "main";

typedef enum
{
    I2C_BUS_SENSORS, // I2C_NUM_0 for main peripherals
    I2C_BUS_OLED,    // I2C_NUM_1 for the display
    I2C_BUS_ALL      // Both buses
} i2c_bus_target_t;

ds3231_t g_rtc;    // Global RTC device handle
bmp280_t g_bmp280; // Global BMP280 device handle
d6fph_t g_d6fph;   // Global D6F-PH device handle

TaskHandle_t g_datalogger_task_handle = NULL;
TaskHandle_t g_uiRender_task_handle = NULL;
i2c_master_bus_handle_t g_i2c_bus0_handle = NULL;
i2c_master_bus_handle_t g_i2c_bus1_handle = NULL;

const config_params_t *g_cfg = NULL;

static uint64_t last_activity_ms = 0;
static bool is_usb_connected_state = false;

static web_server_fsm_state_t s_web_server_state = WEB_SERVER_FSM_IDLE;

// Forward declaration to resolve implicit declaration warning
static void handle_battery_refresh(void)
{
    ESP_LOGI(TAG, "Refreshing battery status on USB state change.");
    if (g_datalogger_cmd_queue != NULL)
    {
        if (xQueueSend(g_datalogger_cmd_queue, &(datalogger_cmd_msg_t){.cmd = DATALOGGER_CMD_REFRESH_BATTERY}, 0) != pdPASS)
        {
            ESP_LOGE(TAG, "Failed to send battery-only refresh command to datalogger queue");
        }
    }
}

static bool handle_stop_web_server(void);

/**
 * @brief Callback for clockwise rotation from the rotary encoder.
 * 
 * This method is executed in the rotary encoder's task context. It sends two messages:
 * 1. A specific event to the uiRender_task for immediate UI updates.
 * 2. A generic activity command to the main_task to reset the sleep timer.
 */
static void on_encoder_rotate_cw(void)
{
    uiRender_send_event(UI_EVENT_CW, NULL, 0);
    app_command_t cmd = {.cmd = APP_CMD_ACTIVITY_DETECTED};
    xQueueSend(g_app_cmd_queue, &cmd, 0);
}

/**
 * @brief Callback for counter-clockwise rotation from the rotary encoder.
 * 
 * This method is executed in the rotary encoder's task context. It sends two messages:
 * 1. A specific event to the uiRender_task for immediate UI updates.
 * 2. A generic activity command to the main_task to reset the sleep timer.
 */
static void on_encoder_rotate_ccw(void)
{

    uiRender_send_event(UI_EVENT_CCW, NULL, 0);
    app_command_t cmd = {.cmd = APP_CMD_ACTIVITY_DETECTED};
    xQueueSend(g_app_cmd_queue, &cmd, 0);
}

/**
 * @brief Callback for button press from the rotary encoder.
 * 
 * This method is executed in the rotary encoder's task context. It sends two messages:
 * 1. A specific event to the uiRender_task for immediate UI updates.
 * 2. A generic activity command to the main_task to reset the sleep timer.
 */
static void on_encoder_button_press(void)
{

    uiRender_send_event(UI_EVENT_BTN, NULL, 0);
    app_command_t cmd = {.cmd = APP_CMD_ACTIVITY_DETECTED};
    xQueueSend(g_app_cmd_queue, &cmd, 0);
}

/**
 * @brief Callback for button long press from the rotary encoder.
 * 
 * This method is executed in the rotary encoder's task context. It sends two messages:
 * 1. A specific event to the uiRender_task for immediate UI updates.
 * 2. A generic activity command to the main_task to reset the sleep timer.
 */
static void on_encoder_button_long_press(void)
{
    uiRender_send_event(UI_EVENT_BTN_LONG, NULL, 0);
    app_command_t cmd = {.cmd = APP_CMD_ACTIVITY_DETECTED};
    xQueueSend(g_app_cmd_queue, &cmd, 0);
}

/**
 * @brief Sets the DS3231 RTC to the application's build time.
 *
 * This function is typically called when the RTC time is found to be invalid
 * at startup. It uses the `__DATE__` and `__TIME__` macros to get the compile
 * time, then sets the RTC and the system time accordingly. It also handles
 * I2C bus mutex and updates a global status variable for UI feedback.
 */
static void handle_set_rtc_to_build_time(void)
{

    esp_err_t ret = ESP_FAIL;
    if (xSemaphoreTake(g_i2c_bus_mutex, portMAX_DELAY))
    {
        ret = ds3231_set_time_to_build_time(&g_rtc);
        xSemaphoreGive(g_i2c_bus_mutex);
    }

    // Update the global command status
    if (xSemaphoreTake(g_command_status_mutex, portMAX_DELAY))
    {
        g_command_status = (ret == ESP_OK) ? CMD_STATUS_SUCCESS : CMD_STATUS_FAIL;
        xSemaphoreGive(g_command_status_mutex);
    }
}

/**
 * @brief Synchronizes the DS3231 RTC with an NTP server.
 *
 * This function retrieves Wi-Fi credentials from the configuration,
 * uses the ntp-client library to get the current UTC time, and then
 * sets the DS3231 RTC and the system time. It provides feedback
 * to the UI via the global command status.
 */
static void handle_sync_rtc_with_ntp(void)
{
    ESP_LOGI(TAG, "Starting NTP time synchronization...");

    // Check if Wi-Fi SSID is configured before attempting to connect.
    if (strlen(g_cfg->wifi_ssid) == 0)
    {
        ESP_LOGE(TAG, "Wi-Fi SSID is not configured. Cannot sync time with NTP.");
        if (xSemaphoreTake(g_command_status_mutex, portMAX_DELAY))
        {
            g_command_status = CMD_STATUS_FAIL;
            xSemaphoreGive(g_command_status_mutex);
        }
        return;
    }

    time_t current_utc_time;
    esp_err_t ret = ntp_client_get_utc_time(g_cfg->wifi_ssid, g_cfg->wifi_password, 30000, &current_utc_time);

    if (ret == ESP_OK)
    {
        ESP_LOGI(TAG, "NTP sync successful. The current UTC time is: %lld", (long long)current_utc_time);

        // Now, set the DS3231 RTC with the obtained time
        if (xSemaphoreTake(g_i2c_bus_mutex, portMAX_DELAY))
        {
            ret = ds3231_set_time_t(&g_rtc, current_utc_time);
            xSemaphoreGive(g_i2c_bus_mutex);
        }

        if (ret == ESP_OK)
        {
            ESP_LOGI(TAG, "DS3231 RTC updated successfully.");
        }
        else
        {
            ESP_LOGE(TAG, "Failed to update DS3231 RTC.");
        }
    }

    // Update the global command status for UI feedback
    if (xSemaphoreTake(g_command_status_mutex, portMAX_DELAY))
    {
        g_command_status = (ret == ESP_OK) ? CMD_STATUS_SUCCESS : CMD_STATUS_FAIL;
        xSemaphoreGive(g_command_status_mutex);
    }
}

/**
 * @brief Powers off the OLED display and suspends the UI rendering task.
 *
 * This function sends a "prepare for sleep" event to the UI, waits for it
 * to be processed, then suspends the UI task and cuts power to the OLED.
 */
static void oled_power_off(void)
{
    // Only act if the UI task exists and is not already suspended.
    if (g_uiRender_task_handle != NULL && eTaskGetState(g_uiRender_task_handle) != eSuspended)
    {
        ESP_LOGI(TAG, "Powering off OLED.");
        vTaskSuspend(g_uiRender_task_handle);
        uiRender_send_event(UI_EVENT_PREPARE_SLEEP, NULL, 0);
        vTaskDelay(pdMS_TO_TICKS(200)); // Give UI time to draw sleep message
        gpio_set_level(OLED_POWER_PIN, 0);
    }
}

/**
 * @brief Powers on the OLED display and resumes the UI rendering task.
 *
 * This function restores power to the OLED, re-initializes the UI driver,
 * resumes the UI task, and sends a "wake up" event. It's called after
 * waking from sleep due to user activity.
 */
static void oled_power_on(void)
{
    // Only act if the UI task exists and is currently suspended.
    if (g_uiRender_task_handle != NULL && eTaskGetState(g_uiRender_task_handle) == eSuspended)
    {
        ESP_LOGI(TAG, "Powering on OLED.");
        gpio_set_level(OLED_POWER_PIN, 1);
        vTaskDelay(pdMS_TO_TICKS(100)); // Wait for OLED to stabilize
        i2c_oled_send_init_commands(I2C_OLED_NUM);
        // Immediately clear the screen and show a "Waking up" message
        // to prevent showing stale "Zzzzz" screen content.
        i2c_oled_clear(I2C_OLED_NUM);
        i2c_oled_write_inverted_text(I2C_OLED_NUM, 0, 0, "System");
        i2c_oled_write_text(I2C_OLED_NUM, 2, 0,0,0, "Waking up...");
        i2c_oled_update_screen(I2C_OLED_NUM);
        vTaskResume(g_uiRender_task_handle);
        uiRender_send_event(UI_EVENT_WAKE_UP, NULL, 0);
    }
}
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
void app_main(void)
{
    // Get wakeup cause
    esp_sleep_wakeup_cause_t cause = esp_sleep_get_wakeup_cause();
    log_wakeup_reason(cause);

    // Disable all wakeup sources after waking up to prevent immediate re-triggering.
    esp_sleep_disable_wakeup_source(ESP_SLEEP_WAKEUP_ALL);

    // Create the initialization event group
    g_init_event_group = xEventGroupCreate();

    // --- Step 1: Initialize GPIO for power control ---
    gpio_config_t oled_pwr_pin_cfg = {
        .pin_bit_mask = (1ULL << OLED_POWER_PIN),
        .mode = GPIO_MODE_OUTPUT,
        .pull_up_en = GPIO_PULLUP_DISABLE,
        .pull_down_en = GPIO_PULLDOWN_DISABLE,
        .intr_type = GPIO_INTR_DISABLE,
    };
    gpio_config(&oled_pwr_pin_cfg);

    gpio_config_t pwr_pin_cfg = {
        .pin_bit_mask = (1ULL << DEVICES_POWER_PIN),
        .mode = GPIO_MODE_OUTPUT,
        .pull_up_en = GPIO_PULLUP_DISABLE,
        .pull_down_en = GPIO_PULLDOWN_DISABLE,
        .intr_type = GPIO_INTR_DISABLE,
    };
    gpio_config(&pwr_pin_cfg);

    // Turn on power for all peripherals.
    gpio_set_level(DEVICES_POWER_PIN, 1);

    // Initialize I2C buses first, as they are needed by peripherals.
    esp_err_t err = i2c_bus_init();
    if (err != ESP_OK)
    {
        ESP_LOGE(TAG, "I2C master initialization failed, stopping.");
        return;
    }

    // --- Early UI Initialization to show boot message ---
    if (cause != ESP_SLEEP_WAKEUP_TIMER)
    {
        // Power on OLED
        gpio_set_level(OLED_POWER_PIN, 1);
        vTaskDelay(pdMS_TO_TICKS(50)); // Wait for OLED power to stabilize
    }
    else
    {
        // Ensure OLED is off for timer-based wakeups
        gpio_set_level(OLED_POWER_PIN, 0);
    }
    vTaskDelay(pdMS_TO_TICKS(50)); // Wait for power to stabilize

    // Initialize UI renderer which will handle its own I2C bus and OLED.
    uiRender_init(g_i2c_bus1_handle, OLED_I2C_ADDR);

    // The uiRender_init function already sends the init commands.
    // Now we clear the buffer, write our message, and update the screen.
    i2c_oled_clear(I2C_OLED_NUM);
    char display_str[21];
    const char *msg = (cause == ESP_SLEEP_WAKEUP_EXT0 || cause == ESP_SLEEP_WAKEUP_GPIO) ? "Waking up..." : "Booting...";
    snprintf(display_str, sizeof(display_str), "%-20s", msg);
    i2c_oled_write_inverted_text(I2C_OLED_NUM, 0, 0, "System");
    i2c_oled_write_text(I2C_OLED_NUM, 2, 0,0,0, display_str);
    i2c_oled_update_screen(I2C_OLED_NUM); 

    // --- Step 2: Initialize RTOS objects (Mutexes and Queues) ---
    g_command_status_mutex = xSemaphoreCreateMutex();
    g_i2c_bus_mutex = xSemaphoreCreateMutex();
    g_sensor_buffer_mutex = xSemaphoreCreateMutex();
    g_app_cmd_queue = xQueueCreate(10, sizeof(app_command_t));
    g_datalogger_cmd_queue = xQueueCreate(5, sizeof(datalogger_cmd_msg_t));

    // --- Step 2.5: Restore State from RTC Memory ---
    if (cause == ESP_SLEEP_WAKEUP_UNDEFINED)
    {
        // This is a cold boot, not a wakeup from sleep. Initialize RTC variables.
        ESP_LOGI(TAG, "First boot, initializing RTC state.");
        rtc_last_write_status = WRITE_STATUS_UNKNOWN;
        rtc_last_successful_write_ts = 0;
        rtc_last_write_attempt_ts = 0;
        rtc_datalogger_mode = DATALOGGER_MODE_NORMAL; // Default to normal on cold boot
        rtc_total_awake_time_s = 0;
    }
    rtc_last_boot_time_ms = esp_timer_get_time() / 1000;

    // Restore the persisted state into the global buffer.
    if (xSemaphoreTake(g_sensor_buffer_mutex, portMAX_DELAY))
    {
        g_sensor_buffer.writeStatus = rtc_last_write_status;
        g_sensor_buffer.last_successful_write_ts = rtc_last_successful_write_ts;
        g_sensor_buffer.last_write_attempt_ts = rtc_last_write_attempt_ts;
        g_sensor_buffer.high_freq_mode_enabled = (rtc_datalogger_mode == DATALOGGER_MODE_HF);
        g_sensor_buffer.datalogger_paused = (rtc_datalogger_mode == DATALOGGER_MODE_PAUSED);
        // Uptime is calculated dynamically in main_task
        xSemaphoreGive(g_sensor_buffer_mutex);
    }

    // --- Step 3: Initialize SD card and Configuration ---
    // Initialize SD card without USB first. The main_task will handle
    // full USB initialization if external power is detected.
    const spi_sdcard_config_t sd_card_pins = {
        .mosi_io_num = SD_CARD_SPI_MOSI_PIN,
        .miso_io_num = SD_CARD_SPI_MISO_PIN,
        .sclk_io_num = SD_CARD_SPI_SCLK_PIN,
        .cs_io_num = SD_CARD_SPI_CS_PIN,
    };
    spi_sdcard_init_sd_only(&sd_card_pins);

    is_usb_connected_state = battery_is_externally_powered();

    // Initialize NVS first, as it's required by other components (like Wi-Fi)
    config_init();

    // Initialize Wi-Fi stack
    wifi_manager_init();

    const char *config_path = "/sdcard/config.ini";
    const char *new_config_path = "/sdcard/config_LOADED.ini";

    // Check if config.ini exists.
    struct stat st;
    if (stat(config_path, &st) == 0)
    {
        // File exists, so load it to flash.
        ESP_LOGI(TAG, "Found %s, loading to flash...", config_path);
        if (config_load_from_sdcard_to_flash(config_path) == ESP_OK)
        {
            ESP_LOGI(TAG, "Config loaded successfully. Renaming to %s", new_config_path);
            // Before renaming, check if the destination file exists and delete it.
            struct stat st_dest;
            if (stat(new_config_path, &st_dest) == 0)
            {
                ESP_LOGI(TAG, "Deleting old %s before renaming.", new_config_path);
                if (unlink(new_config_path) != 0)
                {
                    ESP_LOGE(TAG, "Failed to delete %s: %s", new_config_path, strerror(errno));
                }
            }
            // Rename the file to prevent it from being loaded again on next boot.
            if (rename(config_path, new_config_path) != 0)
            {
                ESP_LOGE(TAG, "Failed to rename config file: %s", strerror(errno));
            }
        }
        else
        {
            ESP_LOGE(TAG, "Failed to load config from SD card into flash.");
        }
    }
    else
    {
        // File not found, which is a normal case.
        // The application will use the configuration already stored in flash.
        ESP_LOGI(TAG, "%s not found. Using stored or default values.", config_path);
    }
    // --- Step 3.5: Read configuration from flash and apply it ---
    config_params_init();
    g_cfg = config_params_get();

    // --- Step 4: Initialize hardware drivers and peripherals ---
    // Initialize Battery Reader first, as it uses ADC which can conflict if I2C is initialized first
    battery_reader_init(BATTERY_ADC_PIN, BATTERY_PWR_PIN, g_cfg->battery_voltage_divider_ratio);

    // --- Step 5: Initialize and validate the external Real-Time Clock (RTC) ---
    bool local_ds3231_available = false;
    err = ds3231_init(&g_rtc, g_i2c_bus0_handle, DS3231_I2C_ADDR);
    struct tm timeinfo;
    time_t rtc_ts = -1;

    if (err != ESP_OK)
    {
        ESP_LOGE(TAG, "DS3231 RTC initialization failed with error: %s", esp_err_to_name(err));
        i2c_bus_deinit(I2C_BUS_SENSORS);
        i2c_bus_init();
        g_rtc.i2c_dev_handle = NULL;
        local_ds3231_available = false;
    }
    else
    {
        local_ds3231_available = true;
        ESP_LOGI(TAG, "DS3231 RTC initialized successfully.");

        // On a cold boot (not a wakeup from deep sleep), apply the default configuration.
        if (cause == ESP_SLEEP_WAKEUP_UNDEFINED)
        {
            ESP_LOGI(TAG, "Cold boot detected. Applying DS3231 default configuration.");
            if (xSemaphoreTake(g_i2c_bus_mutex, portMAX_DELAY))
            {
                ds3231_set_default_config(&g_rtc);
                xSemaphoreGive(g_i2c_bus_mutex);
            }
        }

        // Attempt to read the time from the RTC.
        if (xSemaphoreTake(g_i2c_bus_mutex, portMAX_DELAY))
        {
            if (ds3231_get_time(&g_rtc, &timeinfo) == ESP_OK)
            {
                // Since system TZ is UTC, mktime works like timegm.
                rtc_ts = mktime(&timeinfo);
            }
            xSemaphoreGive(g_i2c_bus_mutex);
        }

        // If RTC read was successful, check if the time is valid.
        if (rtc_ts != -1)
        {
            struct tm build_time;
            sscanf(__DATE__, "%*s %*d %d", &build_time.tm_year);
            build_time.tm_year -= 1900;

            // If RTC year is before build year, set the time
            if (timeinfo.tm_year < build_time.tm_year)
            {
                ESP_LOGW(TAG, "RTC time is invalid. Setting to build time.");
                handle_set_rtc_to_build_time();
            }
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

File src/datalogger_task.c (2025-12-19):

#include "datalogger_task.h"
#include "freertos/FreeRTOS.h"
#include <stdio.h>
#include "freertos/task.h"
#include "freertos/semphr.h"
#include "esp_log.h"
#include "esp_sleep.h"
#include "esp_timer.h"
#include <time.h>
#include <math.h>

#include "../lib/buffers.h"
#include "../lib/i2c_bmp280/i2c_bmp280.h"
#include "../lib/i2c_d6fph/i2c_d6fph.h"
#include "../lib/lipo_battery/lipo_battery.h"
#include "../lib/spi_sdcard/spi_sdcard.h"
#include "../lib/ui/time_utils.h"
#include "../lib/kalman/kalman.h"
#include "../lib/wifi_manager/wifi_manager.h"
#include "config_params.h"

static const char *TAG = "DataloggerTask";

#define SENSOR_REFRESH_INTERVAL_MS 5000

// --- Kalman Filter States ---
// Statically allocated to persist across function calls without using global variables in the header.
// These are no longer RTC_DATA_ATTR. We will re-initialize them on every wake-up
// to ensure a clean and consistent state, preventing corruption from deep sleep cycles.
RTC_DATA_ATTR static kalman_filter_t kf_temperature;
RTC_DATA_ATTR static kalman_filter_t kf_pressure;
RTC_DATA_ATTR static kalman_filter_t kf_diff_pressure;
RTC_DATA_ATTR static kalman_filter_t kf_battery_voltage;
RTC_DATA_ATTR static bool kf_initialized = false;


/**
 * @brief Reads all relevant sensors and updates the global sensor buffer.
 *
 * This function is thread-safe and uses mutexes to protect access to the
 * I2C bus and the shared sensor buffer.
 * @param bmp280_dev Pointer to the initialized BMP280 device descriptor.
 */
static void update_sensor_buffer(datalogger_task_params_t *params)
{
    const int MAX_I2C_RETRIES = 3;
    const config_params_t *cfg = config_params_get();
    const int RETRY_DELAY_MS = 50;
    ESP_LOGD(TAG, "Updating sensor buffer...");

    // --- Read all raw sensor values first ---
    float raw_temperature_c = NAN;
    float raw_diff_pressure_pa = NAN;
    float raw_pressure_kpa = NAN; // Use NAN for consistency
    float raw_battery_voltage = battery_reader_get_voltage();
    bool read_error = false;

    if (xSemaphoreTake(g_i2c_bus_mutex, pdMS_TO_TICKS(2000)) == pdTRUE)
    {
        esp_err_t bmp_err = ESP_FAIL;
        esp_err_t d6fph_err = ESP_FAIL;

        raw_temperature_c = NAN;
        raw_pressure_kpa = NAN;
        if (params->bmp280_available)
        {
            // Use forced mode to ensure sensor is correctly configured for each read.
            // This is more robust, especially after waking from deep sleep.
            long pressure_kpa_long; // Use long for bmp280_force_read

            for (int retries = 0; retries < MAX_I2C_RETRIES; retries++)
            {
                bmp_err = bmp280_force_read(params->bmp280_dev, &raw_temperature_c, &pressure_kpa_long);
                if (bmp_err == ESP_OK)
                    break; // Success, exit retry loop
                vTaskDelay(pdMS_TO_TICKS(RETRY_DELAY_MS));
            }
            if (bmp_err != ESP_OK)
            {
                read_error = true;
                ESP_LOGE(TAG, "BMP280 read failed after %d attempts.", MAX_I2C_RETRIES);
            }
            else
            {
                raw_pressure_kpa = (float)pressure_kpa_long / 1000.0f; // Convert from Pa to kPa
            }
        }
        else
        {
            ESP_LOGI(TAG, "BMP280 not available, skipping temperature and pressure read.");
        }

        raw_diff_pressure_pa = NAN;
        if (params->d6fph_available)
        {
            for (int retries = 0; retries < MAX_I2C_RETRIES; retries++)
            {
                d6fph_err = d6fph_read_pressure(params->d6fph_dev, &raw_diff_pressure_pa);
                if (d6fph_err == ESP_OK)
                    break; // Success, exit retry loop
                vTaskDelay(pdMS_TO_TICKS(RETRY_DELAY_MS));
            }
            if (d6fph_err != ESP_OK)
            {
                read_error = true;
                ESP_LOGE(TAG, "D6F-PH read failed after %d attempts.", MAX_I2C_RETRIES);
            }
        }
        else
        { // d6fph_dev is not initialized
            ESP_LOGI(TAG, "D6F-PH not available, skipping differential pressure read.");
        }

        xSemaphoreGive(g_i2c_bus_mutex);
    }
    else
    {
        read_error = true;
        ESP_LOGE(TAG, "Failed to acquire I2C mutex for sensor readings.");
    }

    // --- Determine which Kalman parameters to use ---
    bool is_hf = false;
    if (xSemaphoreTake(g_sensor_buffer_mutex, 0) == pdTRUE) {
        is_hf = g_sensor_buffer.high_freq_mode_enabled;
        xSemaphoreGive(g_sensor_buffer_mutex);
    }

    // Update filter parameters in the struct
    kf_temperature.q = is_hf ? cfg->kf_temp_q_hf : cfg->kf_temp_q;
    kf_temperature.r = is_hf ? cfg->kf_temp_r_hf : cfg->kf_temp_r;
    kf_pressure.q = is_hf ? cfg->kf_press_q_hf : cfg->kf_press_q;
    kf_pressure.r = is_hf ? cfg->kf_press_r_hf : cfg->kf_press_r;
    kf_diff_pressure.q = is_hf ? cfg->kf_diff_press_q_hf : cfg->kf_diff_press_q;
    kf_diff_pressure.r = is_hf ? cfg->kf_diff_press_r_hf : cfg->kf_diff_press_r;
    kf_battery_voltage.q = is_hf ? cfg->kf_batt_v_q_hf : cfg->kf_batt_v_q;
    kf_battery_voltage.r = is_hf ? cfg->kf_batt_v_r_hf : cfg->kf_batt_v_r;

    // --- Apply Kalman filters if initialized ---
    float filtered_temperature_c = kf_initialized && !isnan(raw_temperature_c) ? kalman_update(&kf_temperature, raw_temperature_c) : raw_temperature_c;

    float filtered_pressure_kpa;
    if (kf_initialized && !isnan(raw_pressure_kpa)) {
        filtered_pressure_kpa = kalman_update(&kf_pressure, raw_pressure_kpa);
    } else {
        filtered_pressure_kpa = raw_pressure_kpa;
    }

    float filtered_diff_pressure_pa = kf_initialized && !isnan(raw_diff_pressure_pa) ? kalman_update(&kf_diff_pressure, raw_diff_pressure_pa) : raw_diff_pressure_pa;
    float filtered_battery_voltage = kf_initialized && !isnan(raw_battery_voltage) ? kalman_update(&kf_battery_voltage, raw_battery_voltage) : raw_battery_voltage;

    // --- Now, lock the buffer and update it with all new values ---
    if (xSemaphoreTake(g_sensor_buffer_mutex, pdMS_TO_TICKS(100)) == pdTRUE)
    {
        g_sensor_buffer.raw_temperature_c = raw_temperature_c;
        g_sensor_buffer.filtered_temperature_c = filtered_temperature_c;

        g_sensor_buffer.raw_pressure_kpa = raw_pressure_kpa;
        g_sensor_buffer.filtered_pressure_kpa = filtered_pressure_kpa;

        g_sensor_buffer.raw_diff_pressure_pa = raw_diff_pressure_pa;
        g_sensor_buffer.filtered_diff_pressure_pa = filtered_diff_pressure_pa;

        // Battery voltage is read outside the I2C mutex
        g_sensor_buffer.raw_battery_voltage = raw_battery_voltage;
        g_sensor_buffer.filtered_battery_voltage = filtered_battery_voltage;
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

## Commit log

2025-08-11 first hello world, reads pressure/temperature from a BMP180 i2c breakout board and prints it to serial
2025-08-11 saving last without lib on i2c lcd
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2025-08-27 feat: Add I2C OLED display support and SPI SD card functionality
    - Implemented I2C communication for OLED display with functions to initialize, clear, and write text.
    - Added SPI SD card support with initialization and CSV writing capabilities.
    - Refactored rotary encoder task for improved state management and responsiveness.
    - Updated main application to integrate OLED display and SD card logging for temperature and pressure readings from BMP180 sensor.
    - Enhanced error handling and logging for SD card operations.
    - Cleaned up I2C configuration for better organization and clarity.
    [main.c]
2025-09-04 sd card mount working
2025-09-15 added bmp280 support, corrected conflict on pin 19-20 which caused i2c failure, tidied up SPI write, added format sd card method (untested), mass storage/local write semaphore still buggy
    [main.c]
2025-09-15 fairly crude and non-thread safe handling of MSC/local write priority, but works. note: writes are blocked as long as the micro is hooked up to a pc, even if it is ejected. not sure about what happen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
2025-09-18 crude, but functioning, fuckups protection on sdcard. apparently tud_ready() is the only method that reliably works, callbacks don't work reliably, tud_mounted will stay true indefinitely once it wen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
2025-09-19 switched to espressif/esp_tinyusb 2.0.0, which sucks ass every bit as bad as 1.7.6 when it comes to MSC mount/unmount callbacks but, apparently, does a better job at figuring if the cable is still co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
2025-09-20 Refactor UI rendering and menu handling;
    menu definition is parametric, nested submenus with scrolling is available.
    add shared sensor data buffer and mutex for thread safety
2025-09-20 improved usb write speed 10X, to approx 5megabit, swapped SPI pins, created release build conf, reenabled jtag on debug one
2025-09-23 -added rtc module support -Refactor sensor buffer structure and integrate DS3231 RTC for timestamp management; -update SD card write functionality to include timestamps from rtc, and use global share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
    all this is amazingly beautiful BUT, sends the esp32 in reboot loop.
    [main.c]
2025-10-02 Refactor SD card logging and UI rendering
    - Updated `spi_sdcard_write_csv` to remove filename parameter and implement file rotation based on size.
    - Introduced a new `datalogger_task` to handle periodic sensor readings and logging to SD card.
    - Improved UI rendering functions to support flicker-free updates and command feedback.
    - Added functionality to set RTC time to build time during initialization.
    - Updated configuration for FAT filesystem to support long filenames.
    - Removed unused settings menu and adjusted menu structure for clarity.
    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
    [datalogger_task.c, main.c]
2025-10-02 first attempt at battery level reads, disabled as it causes reboot loops
    [datalogger_task.c, main.c]
2025-10-08 Enhance battery management features: - Added support for external power detection. - Updated battery reader initialization to include power GPIO. - Improved logging to include battery voltage, percen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
2025-10-09 added olimex esp32 s3 lipo as a module
2025-10-09 first jab at kicad design
2025-10-10 feat: Add sensor data refresh command and enhance rotary encoder functionality
    - Introduced APP_CMD_REFRESH_SENSOR_DATA command in buffers.h for refreshing sensor data.
    - Made gpio_isr_handler public in rotaryencoder.c and added rotaryencoder_enable_wakeup_source function to configure GPIO wake-up sources.
    - Updated rotaryencoder.h to declare new functions and ensure proper IRAM attributes.
    - Enhanced UI rendering logic in ui_render.c to handle sleep and wake events, including new UI_EVENT_PREPARE_SLEEP and UI_EVENT_WAKE_UP events.
    - Refactored datalogger_task.c to improve sensor data updating logic and added a command queue for forced refresh commands.
    - Updated main.c to handle new command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
2025-10-10 fixed timezone display and set everything internal to gmt
    [main.c]
2025-10-10 feat: Enhance battery reader and USB handling in main task - Updated ADC attenuation settings for battery voltage readings. - Added USB connection check for power saving logic in main task. - Introdu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
2025-10-12 power off off devices when sleeping pause and resume functionality for datalogger writes
2025-10-12 feat: Add last successful write timestamp to sensor buffer and update related logic
2025-10-12 first low power mode holding together , with timeouts and wakeups working
2025-10-13 feat: Add BMP280 sensor re-initialization function to improve reliability
2025-10-13 feat: Update DS3231 RTC functions to return esp_err_t for better error handling and add build time setting function several refactors
    [datalogger_task.c, main.c]
2025-10-13 feat: Enhance I2C initialization for BMP280 and DS3231 with default address macros and improve rotary encoder handling refactored rotary encoder to avoid harcoded dependencies resolved warnings on ui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
    [main.c]
2025-10-13 feat: Add detailed documentation for BMP280, DS3231, OLED, and rotary encoder functions
2025-10-13 feat: Pass BMP280 device handle to datalogger task and update sensor buffer function signature
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2025-10-14 made tiny usb reinit optional to save battery, made wake-write-sleep sequence quicker, added last successful write timestamp to storage data page, added "unknown write status" to UI
2025-10-17 -Enhance Datalogger Functionality and Update Rotary Encoder Configuration - Updated the datalogger_task to initialize sensor readings after resuming from sleep, ensuring fresh data is captured. - Cha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
    [DifferentialPressureSensor.kicad_sch]
2025-10-18 feat: Implement configuration management and UI updates for differential pressure sensor
2025-10-18 fix: Enhance OLED power management and deep sleep logic for UI task handling
    [main.c]
2025-10-18 feat: Add global sensor buffer and initialization event group for improved data handling
2025-10-18 feat: Enhance I2C communication with retry logic and increase timeout for BMP280 and D6F-PH sensors
2025-10-19 fixed differential pressure sensor (now it works!), made the omron sensor model parametric, moved i2c oled o he beginning of main,
    [config_sample.ini, main.c]
2025-10-19 fix: Validate Wi-Fi SSID configuration before NTP synchronization
    [main.c]
2025-10-19 feat: Add PCB design documentation for Differential Pressure Datalogger
2025-10-20 feat: Add web server functionality and UI integration
    - Updated UI guide to include web server navigation and functionality.
    - Introduced web server status management in buffers.h.
    - Refactored NTP client to utilize the new Wi-Fi manager for connection handling.
    - Created web server implementation with file listing and download capabilities.
    - Added web server commands to the application command set.
    - Enhanced main application logic to manage web server state and interactions with the datalogger.
    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
    [partitions_custom.csv]
2025-10-20 feat: Improve rotary encoder debounce handling and logging functionality
2025-10-20 feat: Enhance UI with persistent status icons and improve OLED drawing functions
    battery indicard, write failure indicator
2025-10-20 Refactor SD card access management and enhance web server functionality
    - Updated README.md to clarify exclusive file system access rules.
    - Enhanced SOFTWARE_ARCHITECTURE.md with detailed SD card access arbitration.
    - improved exclusive file system access in the main task to prevent data corruption.
    - Improved web server to serve a modern index.html page with file management features.
    - Added API endpoints for file listing and deletion, ensuring safe operations.
    - Implemented Wi-Fi manager deinitialization to free resources on shutdown.
    - Cleaned up code formatting and improved readability across multiple files.
    [main.c]
2025-10-21 updated to new verison of i2c driver, fixed behavior of file resume
    [main.c]
2025-10-22 Refactor datalogger task and buffer management
    - Removed unused datalogger status from sensor buffer.
    - Introduced uptime tracking in the sensor buffer.
    - Updated datalogger task to include uptime in CSV logs.
    - Simplified command handling for pausing and resuming datalogger.
    - Improved sleep logic to ensure proper state management before entering deep sleep.
    - Added smart sleep duration calculation based on logging intervals.
    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
2025-10-22 crash on slep fix
    [main.c]
2025-10-22 Enhance web server functionality and UI updates
    - Improved web server page to allow downloading and previewing logged data files.
    - Added preview feature for CSV files with a user-friendly interface.
    - Updated README and UI guide to reflect new features.
    - Refactored code for better readability and maintainability.
    - fixed sleep logic flaws
    - INFINTE SCROLL ON PREVIEW STILL BROKEN
    [datalogger_task.c, main.c]
2025-10-24 feat(datalogger): add file deletion command and update CSV header
    - Added a new command (DATALOGGER_CMD_DELETE_FILE) to the datalogger task for deleting specified log files.
    - Updated the CSV header to use "datetime_local" instead of "datetime_cet".
    - Modified the logging format to exclude the timezone in the local time string.
    - Removed unnecessary web server pause logic during startup and ensured proper handling of USB connection events.
    - Implemented file existence check and deletion before renaming the configuration file to prevent conflicts.
    - ensure broken conf files are just discarded without afecting curent conf
    - raw file preview in web ui
    - oerhaul of csv view
    [datalogger_task.c, main.c]
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2025-10-24 pause mode and ui overhaul, and ability to run without one or more sensor
2025-10-24 finalized missing sensors management
    [datalogger_task.c]
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2025-10-25 switched to kPA for absolute pressure, improvements to sparkllines
2025-10-26 Fix GPIO pin assignments for SD card and improve pressure reading handling in datalogger
    [datalogger_task.c, main.c]
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2025-10-28 added a feaure to reset ds3231 configuration on each boot.
    [main.c]
2025-10-28 ui MSC mode icon (replaces frequency icons when plugged), refactor to sensor page, removal on non reentrant function usage, refactor of data refresh logic, corrected flaw on batteyr status update, cp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
2025-10-29 fix to datalogger logic
    [datalogger_task.c, main.c]
2025-10-29 Enhance web server functionality and bitmap management
    - Added mutex for scratch buffer in web server to prevent race conditions during file operations.
    - Improved README with detailed explanations of web server features and memory management.
    - Updated bitmap handling in `bitmaps.h` and added new bitmap Excel file.
    - Refactored sleep mode rendering to optimize power usage.
    - Fixed error handling in web server startup process.
    - Added "bitmap editor" xlsx file
    [main.c]
2025-10-29 tidied up kpa/pa conversion, corrected couple of UI flaws
    [datalogger_task.c]
2025-10-31 changes to pin numbers and fixes to rotary encoder to accomodae crappy/noise devices
    [main.c]
2025-10-31 fixed pin numbers, applied optimizations to build file, improved debouncing of rotary encoder
    [main.c]
2025-11-01 updated pins on sch file and completed routing of PCB, sucks bad, but holds togeter with 1 layer only :-D
    [DifferentialPressureSensor.kicad_pcb, DifferentialPressureSensor.kicad_sch]
2025-11-02 fixed error on schematic, applied auto routing, created components bom
    [DifferentialPressureSensor.csv, DifferentialPressureSensor.kicad_pcb, DifferentialPressureSensor.kicad_sch]
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2025-12-17 updaes to kalman filtering, resilience to rebooting and initial uncertainity
    [datalogger_task.c]
2025-12-17 fix to precision in kalman filter to address wonky pressure reads
2025-12-17 fixed a corner case: deletion of the currently active file
2025-12-19 tunin g to kalman, type cast fix on pressure sensor read, last write timestamp persisted across sleeps
    [datalogger_task.c, main.c]
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
